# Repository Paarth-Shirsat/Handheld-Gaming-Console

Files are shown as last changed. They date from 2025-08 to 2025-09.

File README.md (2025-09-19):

# Handheld Gaming Console

---

A Custom STM32-based Board that runs simple games on an LCD, with various peripherals such as IMU, DF-Player Mini, Buttons, Joystick and a Power System.

## PCB Iterations
---
### OLD PCB
---
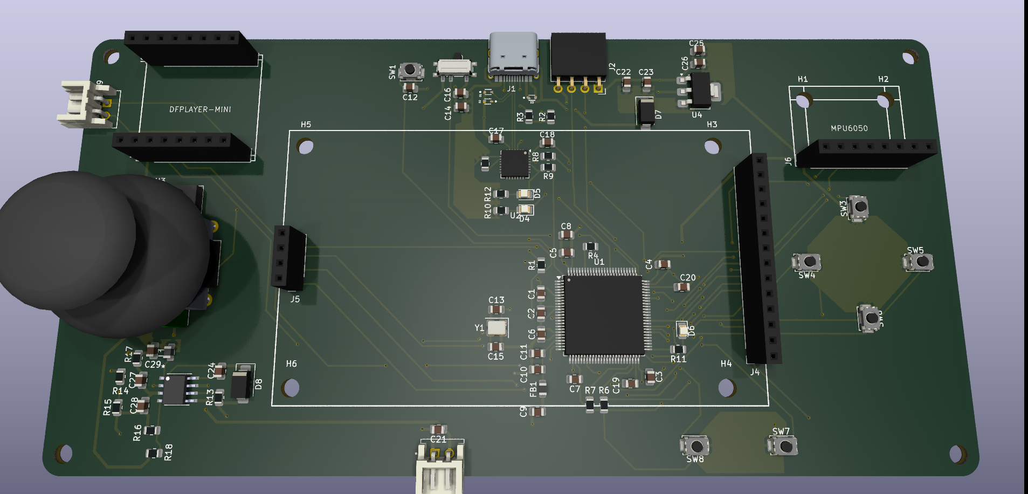
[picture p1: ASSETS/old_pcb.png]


### NEW PCB
---
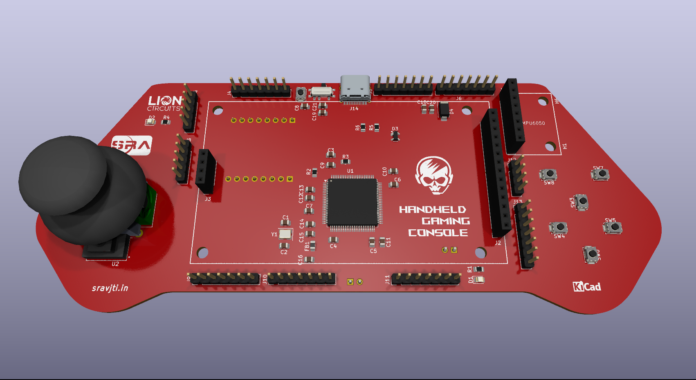
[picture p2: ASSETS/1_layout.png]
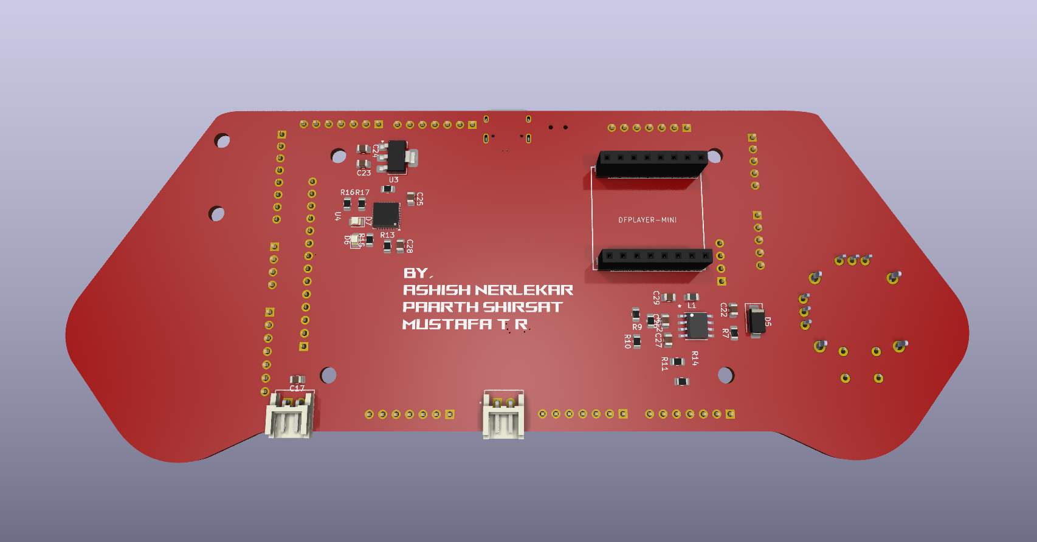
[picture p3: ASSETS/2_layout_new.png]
             

## Table Of Contents

---

- [About The Project](#about-the-project)
    - [Tech Stack](#tech-stack)
    - [File Structure](#file-structure)
- [Getting Started](#getting-started)
    - [Prerequisites](#prerequisites)
        - Hardware
        - Software
    - [Installation](#installation)
- [Usage](#usage)
- [Results And Demo](#results-and-demo)
- [Future Work](#future-work)
- [Contributors](#contributors)
- [Acknowledgements And Resources](#acknowledgements-and-resources)

## About The Project

---

The Handheld Gaming Console is a custom made Printed Circuit Board which utilizes STM32F407VGT6 as its MCU controlling all of the peripherals. The firmware involves setting up all the components and utilizing them to run simple games with the help of controlling hardware such as buttons, joystick and IMU.
The firmware for this project is a bare-metal implementation built on a Hardware Abstraction Layer (HAL). This project is designed to provide hands-on experience and a deep understanding of the embedded development workflow.

This repository will provide all the firmware, PCB files, and steps to use those.

### Tech Stack

---





### File Structure

---

```jsx
Handheld-Gaming-Console/
├── DFPLAYER/
│   ├── dfplayer.c
│   └── dfplayer.h
│
├── HANDHELD/
│   ├── ASSETS/
│   ├── DRIVERS/
│   ├── SRC/
│   └── README.md
│
├── HandHeld-Gaming-Console/
│   ├── .settings/
│   ├── Core/
│   ├── Debug/
│   ├── Drivers/
│   ├── .cproject
│   ├── .mxproject
│   ├── .project
│   ├── HandHeld-Gaming-Console.ioc
│   ├── STM32F407VGTX_FLASH.ld
│   └── STM32F407VGTX_RAM.ld
│
├── Handheld-Nucleo/
│   ├── .settings/
│   ├── Core/
│   ├── Debug/
│   ├── Drivers/
│   ├── CMSIS/
│   ├── GAME/
│   ├── GAME2/
│   ├── MPU6050/
│   ├── STM32F4xx_HAL_Driver/
│   ├── TFT/
│   ├── .cproject
│   ├── .mxproject
│   ├── .project
│   ├── Handheld-Nucleo Debug.launch
│   ├── Handheld-Nucleo.ioc
│   ├── STM32F401RETX_FLASH.ld
│   └── STM32F401RETX_RAM.ld
│
├── PCB Files/
│   ├── HGC PCB.kicad_pcb
│   ├── HGC PROJECT.kicad_pro
│   └── HGC SCHEMATIC.kicad_sch
│
├── UART/
│   ├── uart.c
│   └── uart.h
│
└── README.md
```

## Getting Started

---

### Prerequisites

---

- Hardware
    - STM32 Microcontroller (STM32 Bluepill or Nucleo-F401RE for development)
    - ST-Link V2 or USB-to-TTL adapter (for testing/debugging)
    - Display Driver: ILI9341
    - IMU: MPU6050 (Integrated 6-axis MotionTracking device)
    - MP3 Module: DF-Player Mini
    - Joystick and Buttons
    - Speaker
- Software
    - STM32CubeIDE
    - STM32CubeProgrammer
    - PuTTY (For Serial Monitor)
    - KiCad

### Installation

---

1. Clone the repository

```jsx
git clone https://github.com/Paarth-Shirsat/Handheld-Gaming-Console.git
```

## Usage

---

Steps to flash firmware

1. Connect the console (PCB) to your computer via USB to type C cable.
2. Start the STM32CubeProgrammer.
- By using UART
    1. Select ‘UART’ from the drop-down in the top right. Select the port and set baudrate to ‘115200’ Bd.
    2. Go to ‘Erasing & Programming’ section from the far left part.
    3. Select file path of the ‘.bin’ file from the project folder (search in the ‘Debug’ folder). 
    4. Now, set the BOOT0 pin to high by flicking the switch and click ‘Connect’.
    5. After connecting successfully, click on the ‘Start Programming’ option to start uploading the firmware. A few pop-ups would appear and the board will disconnect automatically.
    6. Now, set the BOOT0 pin to low by again flicking the switch to initial position. Press the ‘Reset’ button on the PCB. You can safely remove the USB to type C cable.
- By using ST-Link
    1. Select ‘UART’ from the drop-down in the top right. Select ‘Serial Number’ and set ‘Port’ as SWD (Serial Wire Debug).
    2. Go to ‘Erasing & Programming’ section from the far left part.
    3. Select file path of the ‘.bin’ file from the project folder (search in the ‘Debug’ folder). 
    4. After the pop-up for flashing of firmware successfully comes, you can safely remove the USB to type C cable.

## Results And Demo

---

Videos of working prototypes are as follows:

Video of Game’s working:

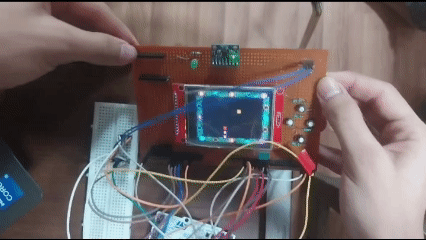
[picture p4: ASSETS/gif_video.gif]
Untitled video - Made with Clipchamp (3).mp4


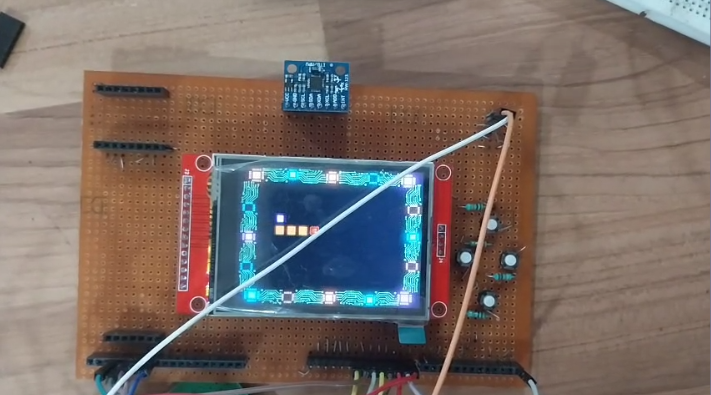
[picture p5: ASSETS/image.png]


## Future Work

---

- [ ]  Addition of sound system

## Contributors

---

- [Ashish Nerlekar](https://github.com/ashish4225)
- [Mustafa T. R.](https://github.com/mt-tass)
- [Paarth Shirsat](https://github.com/Paarth-Shirsat)

## Acknowledgements And Resources

---

- SRA VJTI Eklavya 2025
- Mentors
    - [Vishal Mutha](https://github.com/Vishal-Mutha)
    - [Piyush Patle](https://github.com/PiyushPatle26)
    - [Shaurya Rane](https://github.com/shauryarane05)
- Resources
    - Datasheets for MCU and peripherals utilized.
    - Repository for ILI9341 Library: [Repository Link](https://github.com/afiskon/stm32-ili9341)

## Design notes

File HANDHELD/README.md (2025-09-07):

# HANDHELD GAMING CONSOLE
---
## LIST OF PERIPHERALS
---
[x] BUTTONS
[ ] JOYSTICK
[ ] MPU6050

## LIST OF GAMES
---
[x] SNAKE GAME
[ ] GAME 2
[ ] GAME 3

## PINOUT 
---
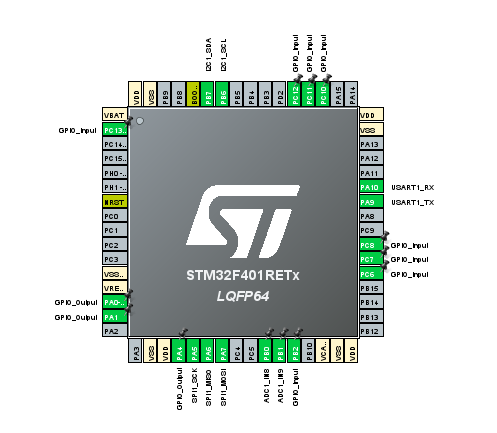
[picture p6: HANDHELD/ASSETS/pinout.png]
Screenshot of the pinout on Nucleo Board


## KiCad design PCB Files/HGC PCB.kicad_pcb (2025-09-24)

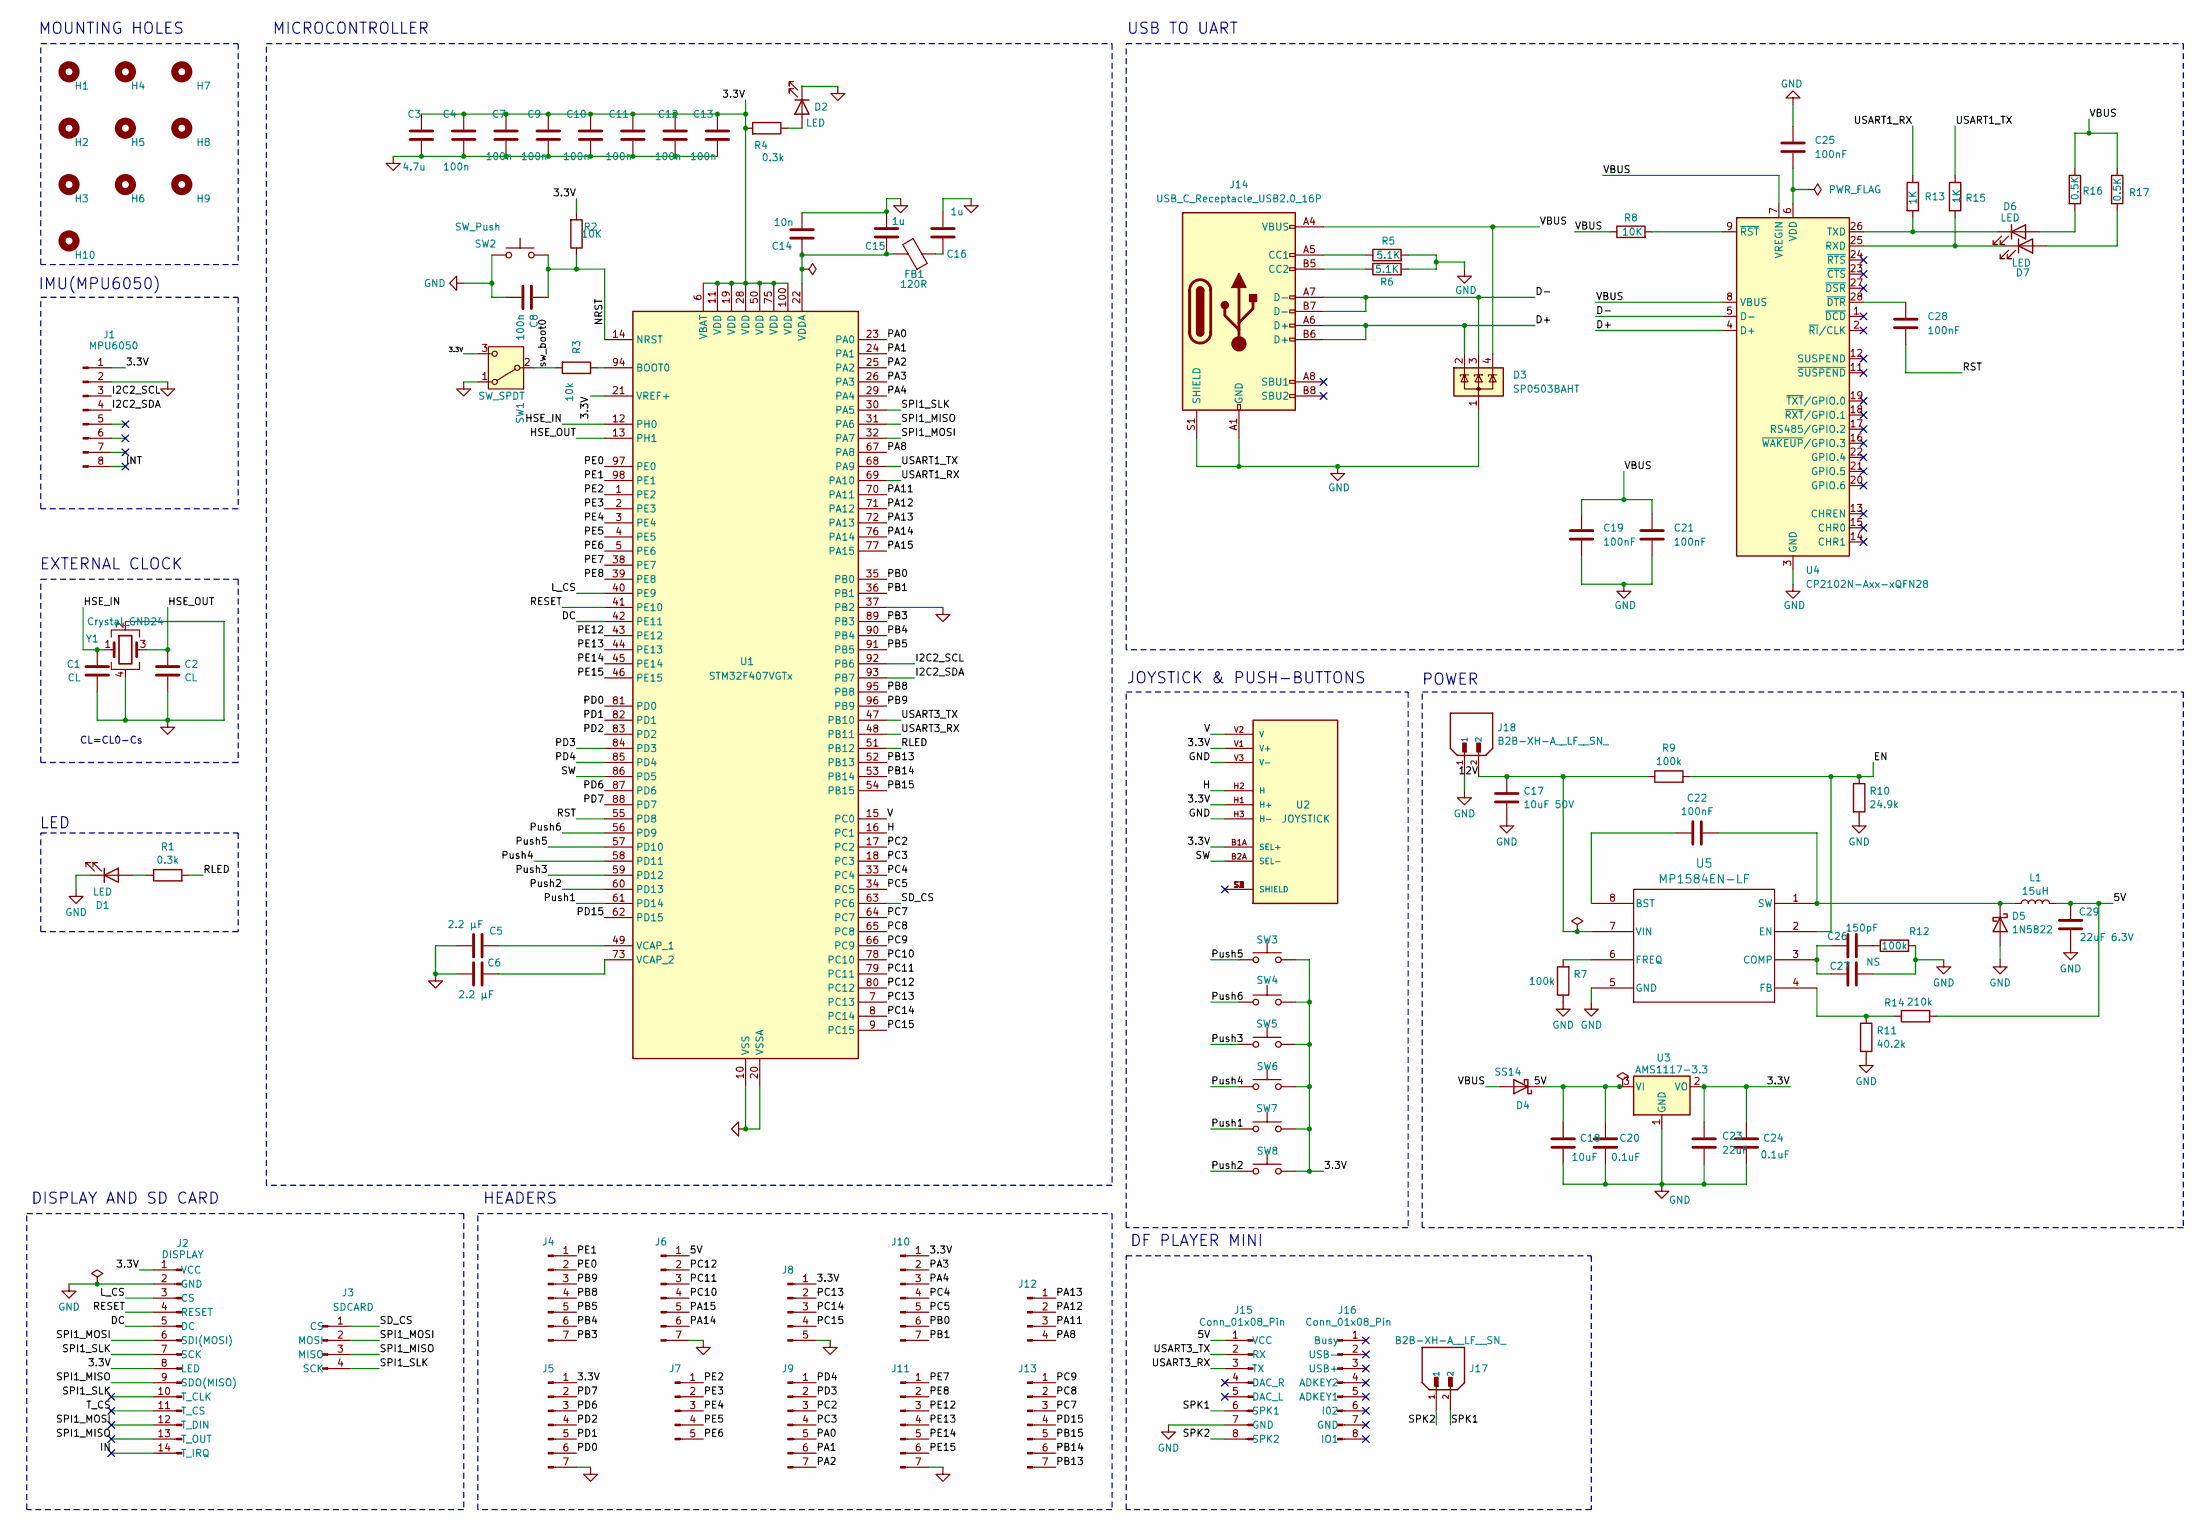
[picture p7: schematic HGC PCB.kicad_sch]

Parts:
C1, C2: CL; C_0805_2012Metric
C3: 4.7u; C_0805_2012Metric
C4, C7, C8, C9, C10, C11, C12, C13: 100n; C_0805_2012Metric
C5, C6: 2.2 µF; C_0805_2012Metric
C14: 10n; C_0805_2012Metric
C15, C16: 1u; C_0805_2012Metric
C17: 10uF 50V; C_0805_2012Metric
C18: 10uF; C_0805_2012Metric
C19, C21, C22, C25, C28: 100nF; C_0805_2012Metric
C20, C24: 0.1uF; C_0805_2012Metric
C23: 22uF; C_0805_2012Metric
C26: 150pF; C_0805_2012Metric
C27: NS; C_0805_2012Metric
C29: 22uF 6.3V; C_0805_2012Metric
D1, D2, D6, D7: LED; LED_0805_2012Metric
D3: SP0503BAHT; SOT-143
D4: SS14; D_SMA
D5: 1N5822; D_SMA
FB1: 120R; L_0805_2012Metric
H1, H2, H3, H4, H5, H6, H7, H8, H9, H10: MountingHole; MountingHole_3.2mm_M3
J1: MPU6050; PinSocket_1x08_P2.54mm_Vertical
J2: DISPLAY; PinSocket_1x14_P2.54mm_Vertical
J3: SDCARD; PinSocket_1x04_P2.54mm_Vertical
J4, J5, J6, J9, J10, J11, J13: Conn_01x07_Pin; PinHeader_1x07_P2.54mm_Vertical
J7, J8: Conn_01x05_Pin; PinHeader_1x05_P2.54mm_Vertical
J12: Conn_01x04_Pin; PinHeader_1x04_P2.54mm_Vertical
J14: USB_C_Receptacle_USB2.0_16P; USB_C_Receptacle_HRO_TYPE-C-31-M-12
J15, J16: Conn_01x08_Pin; PinSocket_1x08_P2.54mm_Vertical
J17, J18: B2B-XH-A__LF__SN_; JST_B2B-XH-A__LF__SN_; PARTREV N/A
L1: 15uH; L_0805_2012Metric
R1, R4: 0.3k; R_0805_2012Metric
R2, R8: 10K; R_0805_2012Metric
R3: 10k; R_0805_2012Metric
R5, R6: 5.1K; R_0805_2012Metric
R7, R9, R12: 100k; R_0805_2012Metric
R10: 24.9k; R_0805_2012Metric
R11: 40.2k; R_0805_2012Metric
R13, R15: 1K; R_0805_2012Metric
R14: 210k; R_0805_2012Metric
R16, R17: 0.5K; R_0805_2012Metric
SW1: SW_SPDT; SW_SPDT_PCM12
SW2: SW_Push; SW_Push_SPST_NO_Alps_SKRK
SW3, SW4, SW5, SW6, SW7, SW8: SW_Push; SW_Push_1P1T_NO_CK_KSC7xxJ
U1: STM32F407VGTx; LQFP-100_14x14mm_P0.5mm
U2: JOYSTICK; XDCR_COM-09032; PARTREV N/A
U3: AMS1117-3.3; SOT-223-3_TabPin2
U4: CP2102N-Axx-xQFN28; QFN-28-1EP_5x5mm_P0.5mm_EP3.35x3.35mm
U5: MP1584EN-LF; SOIC8E_MPS
Y1: Crystal_GND24; Crystal_SMD_3225-4Pin_3.2x2.5mm

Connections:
/3.3V: C3.1, C4.1, C7.1, C9.1, C10.1, C11.1, C12.1, C13.1, C23.1, C24.1, J1.1, J2.1 (VCC), J2.8 (LED), J5.1, J8.1, J10.1, R2.2, R4.2, SW1.3 (C), SW3.1, SW4.1, SW5.1, SW6.1, SW7.1, SW8.1, U1.6 (VBAT), U1.11 (VDD), U1.19 (VDD), U1.21 (VREF+), U1.28 (VDD), U1.50 (VDD), U1.75 (VDD), U1.100 (VDD), U2.B1A (SEL+), U2.H1 (H+), U2.V1 (V+), U3.2 (VO)
/5V: C18.1, C20.1, C29.1, D4.1 (K), J6.1, J15.1 (VCC), L1.2, R14.2, U3.3 (VI)
/12V: C17.1, J18.2, R9.1, U5.7 (VIN)
/D+: D3.2 (K), J14.A6 (D+), J14.B6 (D+), U4.4 (D+)
/D-: D3.3 (K), J14.A7 (D-), J14.B7 (D-), U4.5 (D-)
/DC: J2.5 (DC), U1.42 (PE11)
/EN: R9.2, R10.1, U5.2 (EN)
/H: U1.16 (PC1), U2.H2 (H)
/HSE_IN: C1.2, U1.12 (PH0), Y1.1
/HSE_OUT: C2.2, U1.13 (PH1), Y1.3
/I2C2_SCL: J1.3, U1.92 (PB6)
/I2C2_SDA: J1.4, U1.93 (PB7)
/IN: J2.14 (T_IRQ)
/INT: J1.8
/L_CS: J2.3 (CS), U1.40 (PE9)
/NRST: C8.2, R2.1, SW2.2, U1.14 (NRST)
/PA0: J9.5, U1.23 (PA0)
/PA1: J9.6, U1.24 (PA1)
/PA2: J9.7, U1.25 (PA2)
/PA3: J10.2, U1.26 (PA3)
/PA4: J10.3, U1.29 (PA4)
/PA8: J12.4, U1.67 (PA8)
/PA11: J12.3, U1.70 (PA11)
/PA12: J12.2, U1.71 (PA12)
/PA13: J12.1, U1.72 (PA13)
/PA14: J6.6, U1.76 (PA14)
/PA15: J6.5, U1.77 (PA15)
/PB0: J10.6, U1.35 (PB0)
/PB1: J10.7, U1.36 (PB1)
/PB3: J4.7, U1.89 (PB3)
/PB4: J4.6, U1.90 (PB4)
/PB5: J4.5, U1.91 (PB5)
/PB8: J4.4, U1.95 (PB8)
/PB9: J4.3, U1.96 (PB9)
/PB13: J13.7, U1.52 (PB13)
/PB14: J13.6, U1.53 (PB14)
/PB15: J13.5, U1.54 (PB15)
/PC2: J9.3, U1.17 (PC2)
/PC3: J9.4, U1.18 (PC3)
/PC4: J10.4, U1.33 (PC4)
/PC5: J10.5, U1.34 (PC5)
/PC7: J13.3, U1.64 (PC7)
/PC8: J13.2, U1.65 (PC8)
/PC9: J13.1, U1.66 (PC9)
/PC10: J6.4, U1.78 (PC10)
/PC11: J6.3, U1.79 (PC11)
/PC12: J6.2, U1.80 (PC12)
/PC13: J8.2, U1.7 (PC13)
/PC14: J8.3, U1.8 (PC14)
/PC15: J8.4, U1.9 (PC15)
/PD0: J5.6, U1.81 (PD0)
/PD1: J5.5, U1.82 (PD1)
/PD2: J5.4, U1.83 (PD2)
/PD3: J9.2, U1.84 (PD3)
/PD4: J9.1, U1.85 (PD4)
/PD6: J5.3, U1.87 (PD6)
/PD7: J5.2, U1.88 (PD7)
/PD15: J13.4, U1.62 (PD15)
/PE0: J4.2, U1.97 (PE0)
/PE1: J4.1, U1.98 (PE1)
/PE2: J7.1, U1.1 (PE2)
/PE3: J7.2, U1.2 (PE3)
/PE4: J7.3, U1.3 (PE4)
/PE5: J7.4, U1.4 (PE5)
/PE6: J7.5, U1.5 (PE6)
/PE7: J11.1, U1.38 (PE7)
/PE8: J11.2, U1.39 (PE8)
/PE12: J11.3, U1.43 (PE12)
/PE13: J11.4, U1.44 (PE13)
/PE14: J11.5, U1.45 (PE14)
/PE15: J11.6, U1.46 (PE15)
/Push1: SW7.2, U1.61 (PD14)
/Push2: SW8.2, U1.60 (PD13)
/Push3: SW5.2, U1.59 (PD12)
/Push4: SW6.2, U1.58 (PD11)
/Push5: SW3.2, U1.57 (PD10)
/Push6: SW4.2, U1.56 (PD9)
/RESET: J2.4 (RESET), U1.41 (PE10)
/RLED: R1.2, U1.51 (PB12)
/RST: C28.1, U1.55 (PD8)
/SD_CS: J3.1 (CS), U1.63 (PC6)
/SPI1_MISO: J2.9 (SDO(MISO)), J2.13 (T_OUT), J3.3 (MISO), U1.31 (PA6)
/SPI1_MOSI: J2.6 (SDI(MOSI)), J2.12 (T_DIN), J3.2 (MOSI), U1.32 (PA7)
/SPI1_SLK: J2.7 (SCK), J2.10 (T_CLK), J3.4 (SCK), U1.30 (PA5)
/SPK1: J15.6 (SPK1), J17.2
/SPK2: J15.8 (SPK2), J17.1
/SW: U1.86 (PD5), U2.B2A (SEL-)
/T_CS: J2.11 (T_CS)
/USART1_RX: R13.1, U1.69 (PA10)
/USART1_TX: R15.1, U1.68 (PA9)
/USART3_RX: J15.3 (TX), U1.48 (PB11)
/USART3_TX: J15.2 (RX), U1.47 (PB10)
/V: U1.15 (PC0), U2.V2 (V)
/VBUS: C19.1, C21.1, D3.4 (K), D4.2 (A), J14.A4 (VBUS), J14.A9 (VBUS), J14.B4 (VBUS), J14.B9 (VBUS), R8.1, R16.1, R17.1, U4.7 (VREGIN), U4.8 (VBUS)
/sw_boot0: R3.2, SW1.2 (B)
GND: C1.1, C2.1, C3.2, C4.2, C5.2, C6.2, C7.2, C8.1, C9.2, C10.2, C11.2, C12.2, C13.2, C14.2, C15.2, C16.2, C17.2, C18.2, C19.2, C20.2, C21.2, C23.2, C24.2, C25.1, C27.2, C29.2, D1.1 (K), D2.1 (K), D3.1 (A), D5.2 (A), J1.2, J2.2 (GND), J5.7, J6.7, J8.5, J11.7, J14.A1 (GND), J14.A12 (GND), J14.B1 (GND), J14.B12 (GND), J14.S1 (SHIELD), J15.7 (GND), J18.1, R5.2, R6.2, R7.1, R10.2, R11.2, R12.2, SW1.1 (A), SW2.1, U1.10 (VSS), U1.20 (VSSA), U1.27 (VSS), U1.37 (PB2), U1.74 (VSS), U1.99 (VSS), U2.H3 (H-), U2.V3 (V-), U3.1 (GND), U4.3 (GND), U4.29 (GND), U5.5 (GND), Y1.2, Y1.4
unnamed: C16.1, FB1.1
unnamed: C26.2, R12.1
unnamed: D1.2 (A), R1.1
unnamed: D2.2 (A), R4.1
unnamed: C22.1, D5.1 (K), L1.1, U5.1 (SW)
unnamed: D6.2 (A), R16.2
unnamed: D6.1 (K), R13.2, U4.26 (TXD)
unnamed: D7.2 (A), R17.2
unnamed: D7.1 (K), R15.2, U4.25 (RXD)
unnamed: J14.A5 (CC1), R5.1
unnamed: J14.B5 (CC2), R6.1
unnamed: R3.1, U1.94 (BOOT0)
unnamed: C5.1, U1.49 (VCAP_1)
unnamed: C6.1, U1.73 (VCAP_2)
unnamed: C14.1, C15.1, FB1.2, U1.22 (VDDA)
unnamed: C25.2, U4.6 (VDD)
unnamed: C28.2, U4.28 (~DTR)
unnamed: R8.2, U4.9 (~RST)
unnamed: C22.2, U5.8 (BST)
unnamed: C26.1, C27.1, U5.3 (COMP)
unnamed: R11.1, R14.1, U5.4 (FB)
unnamed: R7.2, U5.6 (FREQ)

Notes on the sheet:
JOYSTICK & PUSH-BUTTONS
MOUNTING HOLES
DF PLAYER MINI
EXTERNAL CLOCK
MICROCONTROLLER
LED
DISPLAY AND SD CARD
USB TO UART
IMU(MPU6050)
HEADERS
CL=CL0-Cs
POWER

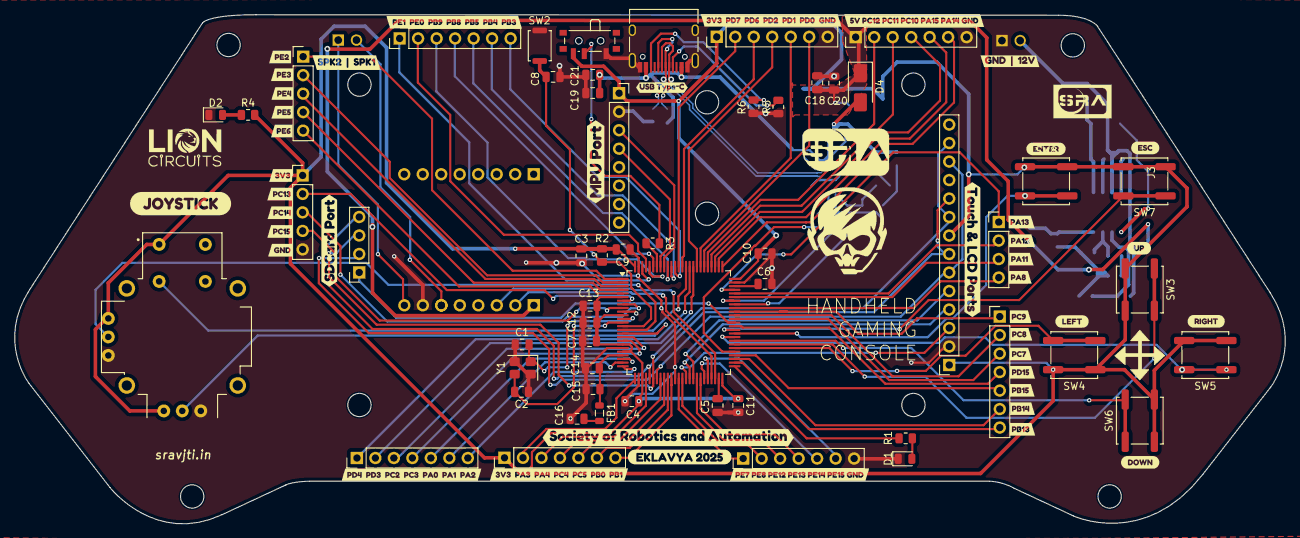
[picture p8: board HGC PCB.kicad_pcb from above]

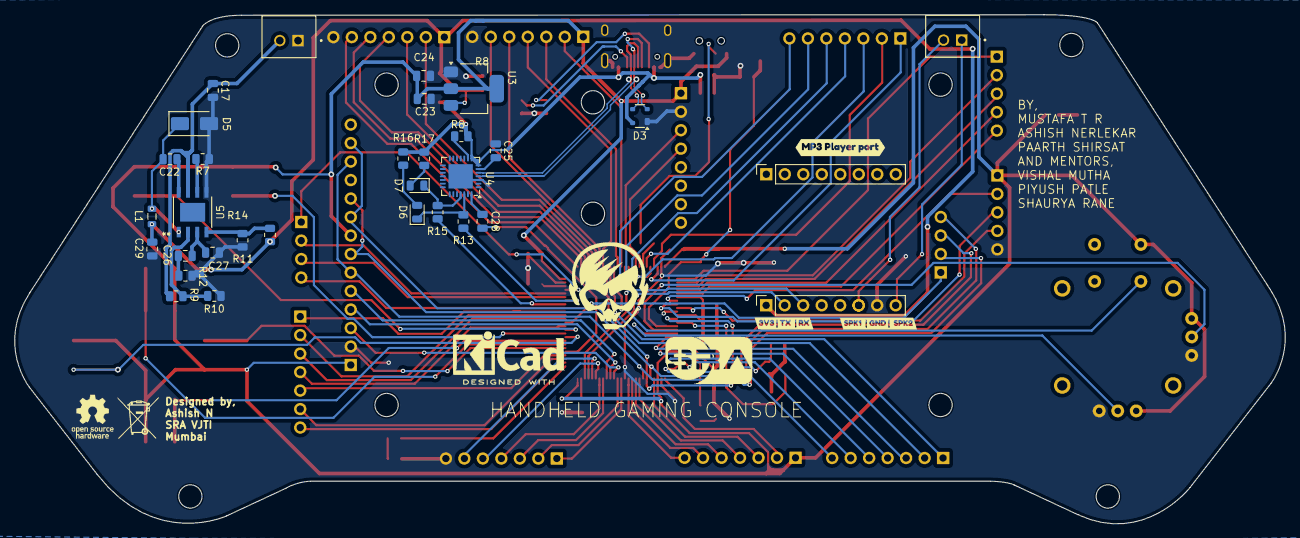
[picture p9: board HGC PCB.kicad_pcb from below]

Board: 2 copper layers, 174.5 x 69.9 mm, 142 parts (35 on the bottom side), 115 nets.

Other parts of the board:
kibuzzard-68C92F98: G***; kibuzzard-68C92F98
kibuzzard-68C92FA3: G***; kibuzzard-68C92FA3
kibuzzard-68C92FAB: G***; kibuzzard-68C92FAB
kibuzzard-68C92FB6: G***; kibuzzard-68C92FB6
kibuzzard-68C92FBD: G***; kibuzzard-68C92FBD
kibuzzard-68C92FC5: G***; kibuzzard-68C92FC5
kibuzzard-68C92FCD: G***; kibuzzard-68C92FCD
kibuzzard-68C92FD9: G***; kibuzzard-68C92FD9
kibuzzard-68C92FE3: G***; kibuzzard-68C92FE3
kibuzzard-68C92FEC: G***; kibuzzard-68C92FEC
kibuzzard-68C92FF6: G***; kibuzzard-68C92FF6
kibuzzard-68C93B2B: G***; kibuzzard-68C93B2B
kibuzzard-68C93B18: G***; kibuzzard-68C93B18
kibuzzard-68C93D93: G***; kibuzzard-68C93D93
kibuzzard-68C922D4: G***; kibuzzard-68C922D4
kibuzzard-68C923AF: G***; kibuzzard-68C923AF
kibuzzard-68C923C7: G***; kibuzzard-68C923C7
kibuzzard-68C923F6: G***; kibuzzard-68C923F6
kibuzzard-68C930B6: G***; kibuzzard-68C930B6
kibuzzard-68C930DF: G***; kibuzzard-68C930DF
kibuzzard-68C930EB: G***; kibuzzard-68C930EB
kibuzzard-68C931DF: G***; kibuzzard-68C931DF
kibuzzard-68C931ED: G***; kibuzzard-68C931ED
kibuzzard-68C939EA: G***; kibuzzard-68C939EA
kibuzzard-68C9310A: G***; kibuzzard-68C9310A
kibuzzard-68C9319C: G***; kibuzzard-68C9319C
kibuzzard-68C9320A: G***; kibuzzard-68C9320A
kibuzzard-68C9322C: G***; kibuzzard-68C9322C
kibuzzard-68C9330F: G***; kibuzzard-68C9330F
kibuzzard-68C9333E: G***; kibuzzard-68C9333E
kibuzzard-68C92324: G***; kibuzzard-68C92324
kibuzzard-68C93061: G***; kibuzzard-68C93061
kibuzzard-68C93086: G***; kibuzzard-68C93086
kibuzzard-68C93097: G***; kibuzzard-68C93097
kibuzzard-68C93100: G***; kibuzzard-68C93100
kibuzzard-68C93116: G***; kibuzzard-68C93116
kibuzzard-68C93123: G***; kibuzzard-68C93123
kibuzzard-68C93223: G***; kibuzzard-68C93223
kibuzzard-68C93326: G***; kibuzzard-68C93326
kibuzzard-68C93356: G***; kibuzzard-68C93356
kibuzzard-68CBCDEB: G***; kibuzzard-68CBCDEB
kibuzzard-68CBF0D1: G***; kibuzzard-68CBF0D1
kibuzzard-68D3B1B5: G***; kibuzzard-68D3B1B5
kibuzzard-668FE423: G***; kibuzzard-668FE423
kibuzzard-675FDA6A: G***; kibuzzard-675FDA6A

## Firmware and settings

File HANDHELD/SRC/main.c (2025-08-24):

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
/* Includes ------------------------------------------------------------------*/
#include "main.h"
#include <stdbool.h>
#include <string.h>
#include "snake.h"
#include "ili9341.h"
#include "fonts.h"

/* USER CODE BEGIN PTD */
typedef struct{
	const char *name;
	int id , x, y , height , width , textx , texty;
} items;

/* USER CODE END PTD */

/* USER CODE BEGIN PD */
#define STATE_MENU 1
#define STATE_GAME1 2
#define STATE_GAME2 3
#define STATE_OVER 4
#define GPIO_UP_PO GPIOC
#define GPIO_UP_PIN GPIO_PIN_10
#define GPIO_DOWN_PO GPIOC
#define GPIO_DOWN_PIN GPIO_PIN_11
#define GPIO_LEFT_PO GPIOC
#define GPIO_LEFT_PIN GPIO_PIN_6
#define GPIO_RIGHT_PO GPIOC
#define GPIO_RIGHT_PIN GPIO_PIN_7
#define GPIO_BUTTON1_PO GPIOC
#define GPIO_BUTTON2_PO GPIOC
#define GPIO_BUTTON1_PIN GPIO_PIN_13
#define GPIO_BUTTON2_PIN GPIO_PIN_8
#define CHANNEL_X ADC_CHANNEL_8
#define CHANNEL_Y ADC_CHANNEL_9
#define JOYSTICK_BUTTON_PO GPIOB
#define JOYSTICK_BUTTON_PIN GPIO_PIN_2

/* USER CODE END PD */

ADC_HandleTypeDef hadc1;

I2C_HandleTypeDef hi2c1;

SPI_HandleTypeDef hspi1;

UART_HandleTypeDef huart1;

/* USER CODE BEGIN PV */
int current_state = STATE_MENU;
int current_menu_index = 0;
items item[] = {{"Snake Game" , 1 , 50 , 50 , 220 , 50 ,105 ,66} , {"Game2 (in progress)" , 2 , 50 , 120 , 220 , 50 ,50 ,136}} ;
int menu_length = 2;
/* USER CODE END PV */

void SystemClock_Config(void);
static void MX_GPIO_Init(void);
static void MX_ADC1_Init(void);
static void MX_I2C1_Init(void);
static void MX_SPI1_Init(void);
static void MX_USART1_UART_Init(void);
/* USER CODE BEGIN PFP */
uint16_t getADC(uint32_t channel){
	ADC_ChannelConfTypeDef adc_confg = {0};
	adc_confg.Channel = channel;
	adc_confg.Rank = 1;
	adc_confg.SamplingTime = ADC_SAMPLETIME_56CYCLES;
	HAL_ADC_ConfigChannel(&hadc1,&adc_confg);
	HAL_ADC_Start(&hadc1);
	HAL_ADC_PollForConversion(&hadc1 , HAL_MAX_DELAY);
	uint16_t val = HAL_ADC_GetValue(&hadc1);
	HAL_ADC_Stop(&hadc1);
	return val;
}
bool getButton(GPIO_TypeDef *GPIOP , uint16_t GPIOPIN){
	if (HAL_GPIO_ReadPin(GPIOP,GPIOPIN)==GPIO_PIN_SET){
		return true;
	}
	return false;
}

/* USER CODE END PFP */

/**
  * @brief  The application entry point.
  * @retval int
  */
int main(void)
{

  /* MCU Configuration--------------------------------------------------------*/

  /* Reset of all peripherals, Initializes the Flash interface and the Systick. */
  HAL_Init();

  /* Configure the system clock */
  SystemClock_Config();

  /* Initialize all configured peripherals */
  MX_GPIO_Init();
  MX_ADC1_Init();
  MX_I2C1_Init();
  MX_SPI1_Init();
  MX_USART1_UART_Init();
  /* USER CODE BEGIN 2 */
  ILI9341_Init();
  ILI9341_FillScreen(ILI9341_BLACK);
  current_menu_index = 0;
  bool firstdraw = true;

  /* USER CODE END 2 */

  /* Infinite loop */
  /* USER CODE BEGIN WHILE */
  while (1)
  {
    /* USER CODE END WHILE */
	  if(current_state == STATE_MENU){
		  if(getButton(GPIO_UP_PO , GPIO_UP_PIN)){
			  current_menu_index -= 1;
			  if(current_menu_index < 0){
				  current_menu_index=menu_length-1;
			  }
			  for(int i = 0 ; i < menu_length ; i++){
				  ILI9341_FillRectangle(item[i].x , item[i].y,item[i].width,item[i].height,ILI9341_BLACK);
			  }
			  for(int i = 0 ; i < menu_length ; i++){
				  uint16_t color = ILI9341_BLUE;
				  uint16_t color_text = ILI9341_WHITE;
				  if(current_menu_index == i){
					  color = ILI9341_CYAN;
					  color_text = ILI9341_BLACK;
				  }
				  ILI9341_FillRectangle(item[i].x , item[i].y,item[i].width,item[i].height,color);
				  ILI9341_WriteString(item[i].textx,item[i].texty,item[i].name,Font_11x18,color_text,color);

			  }
			  char title[]="SELECT A GAME";
			  ILI9341_WriteString(56,10,title,Font_16x26,ILI9341_WHITE,ILI9341_BLACK);
		  }
		  if(getButton(GPIO_DOWN_PO , GPIO_DOWN_PIN)){
		  			  current_menu_index += 1;
		  			  if(current_menu_index > menu_length-1){
		  				  current_menu_index= 0;
		  			  }
		  			  for(int i = 0 ; i < menu_length ; i++){
		  				  ILI9341_FillRectangle(item[i].x , item[i].y,item[i].width,item[i].height,ILI9341_BLACK);
		  			  }
		  			  for(int i = 0 ; i < menu_length ; i++){
		  				  uint16_t color = ILI9341_BLUE;
		  				  uint16_t color_text = ILI9341_WHITE;
		  				  if(current_menu_index == i){
		  					  color = ILI9341_CYAN;
		  					  color_text = ILI9341_BLACK;
		  				  }
		  				  ILI9341_FillRectangle(item[i].x , item[i].y,item[i].width,item[i].height,color);
		  				  ILI9341_WriteString(item[i].textx,item[i].texty,item[i].name,Font_11x18,color_text,color);

		  			  }
		  			  char title[]="SELECT A GAME";
		  			  ILI9341_WriteString(56,10,title,Font_16x26,ILI9341_WHITE,ILI9341_BLACK);
		  		  }
		  if(getButton(GPIO_BUTTON1_PO , GPIO_BUTTON1_PIN)){
		  			  if(item[current_menu_index].id == 1){
		  				  ILI9341_FillScreen(ILI9341_BLACK);
		  				  SNAKE_Init();
		  				  current_state = STATE_GAME1;
		  			  }

	  }
		  if(firstdraw){
			  for(int i = 0 ; i < menu_length ; i++){
			  				  ILI9341_FillRectangle(item[i].x , item[i].y,item[i].width,item[i].height,ILI9341_BLACK);
			  			  }
			  			  for(int i = 0 ; i < menu_length ; i++){
			  				  uint16_t color = ILI9341_BLUE;
			  				  uint16_t color_text = ILI9341_WHITE;
			  				  if(current_menu_index == i){
			  					  color = ILI9341_CYAN;
			  					  color_text = ILI9341_BLACK;
			  				  }
			  				  ILI9341_FillRectangle(item[i].x , item[i].y,item[i].width,item[i].height,color);
			  				  ILI9341_WriteString(item[i].textx,item[i].texty,item[i].name,Font_11x18,color_text,color);

			  			  }
			  			  char title[]="SELECT A GAME";
			  			  ILI9341_WriteString(56,10,title,Font_16x26,ILI9341_WHITE,ILI9341_BLACK);

			  			  firstdraw = false;

		  }

    /* USER CODE BEGIN 3 */
  }

	  else if (current_state == STATE_OVER){
		  ILI9341_FillScreen(ILI9341_RED);
		  if(getButton(GPIO_BUTTON1_PO , GPIO_BUTTON1_PIN)){
		  		  			  firstdraw = true;
		  		  			  current_state = 	STATE_MENU;
		  		  			  }

	  }
	  else if(current_state == STATE_GAME1){  //snake game part
		  if(getButton(GPIO_UP_PO , GPIO_UP_PIN)){
			  SNAKE_ChangeDirection(4);
		  }
		  if(getButton(GPIO_DOWN_PO,GPIO_UP_PIN)){
			  SNAKE_ChangeDirection(2);
		  }
		  if(getButton(GPIO_LEFT_PO,GPIO_LEFT_PIN)){
		  	  SNAKE_ChangeDirection(3);
		  }
		  if(getButton(GPIO_RIGHT_PO,GPIO_RIGHT_PIN)){
		  	  SNAKE_ChangeDirection(1);
		  }
		  bool gameover = SNAKE_getOver();
		  if(!gameover){
			  SNAKE_updateGame();
			  SNAKE_drawGame();
			  HAL_Delay(100);
		  }
		  else{
			  current_state = STATE_OVER;
		  }
	  }

  /* USER CODE END 3 */
}
}
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


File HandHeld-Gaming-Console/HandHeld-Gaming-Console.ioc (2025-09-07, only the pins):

Mcu.UserName=STM32F407VGTx
PA0-WKUP.Signal=UART4_TX
PA1.Signal=UART4_RX
PA4.Signal=ADCx_IN4
PA6.Signal=ADCx_IN6
PB0.Signal=GPIO_Input
PB10.Signal=I2C2_SCL
PB11.Signal=I2C2_SDA
PB13.Signal=SPI2_SCK
PB2.Signal=GPIO_Input
PC13-ANTI_TAMP.Signal=GPIO_Output
PC2.Signal=SPI2_MISO
PC3.Signal=SPI2_MOSI
PC4.Signal=GPIO_Input
PE10.Signal=GPIO_Input
PE12.Signal=GPIO_Input
PE4.Signal=GPIO_Output
PE6.Signal=GPIO_Output
PE8.Signal=GPIO_Input
PH0-OSC_IN.Signal=RCC_OSC_IN
PH1-OSC_OUT.Signal=RCC_OSC_OUT

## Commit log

2025-09-07 Added Hardware Files
    [HGC PCB.kicad_pcb, HGC SCHEMATIC.kicad_sch]
2025-09-23 pcb updated
    [HGC PCB.kicad_pcb, HGC PCB.kicad_sch]
2025-09-23 pcb updated again
    [HGC PCB.kicad_pcb]
2025-09-23 pcb updated for final review
    [HGC PCB.kicad_pcb]

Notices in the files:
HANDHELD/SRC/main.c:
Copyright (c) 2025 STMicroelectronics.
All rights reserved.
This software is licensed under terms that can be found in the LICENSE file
